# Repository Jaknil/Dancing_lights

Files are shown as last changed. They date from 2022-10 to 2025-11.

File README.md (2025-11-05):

# Dancing_lights
Dancing lights is an interactive sensitive light installation where 180 (was 300) programmable LEDs in a tube filled with crushed glass responds to movement by sensing the induced voltage from static electricity stored in people into an old TV antenna.

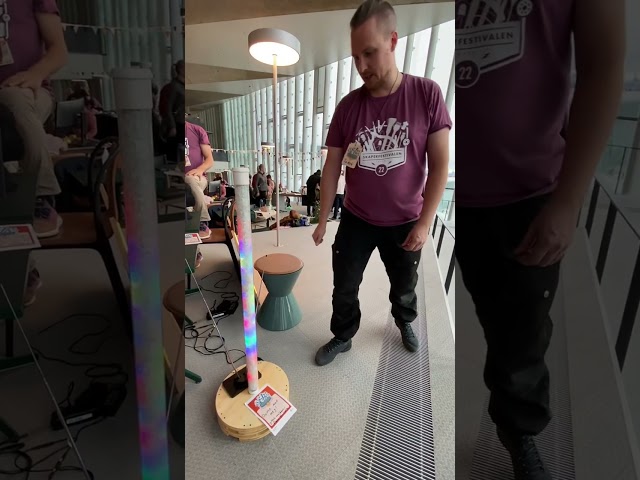
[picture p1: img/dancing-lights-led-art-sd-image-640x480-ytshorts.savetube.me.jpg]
Video demo from Skaperfesivalen (https://youtube.com/shorts/MSAI1wNTsRs)


[Video demo from Oslo skaperfestival 2022 at Deichman library](https://youtube.com/shorts/MSAI1wNTsRs)

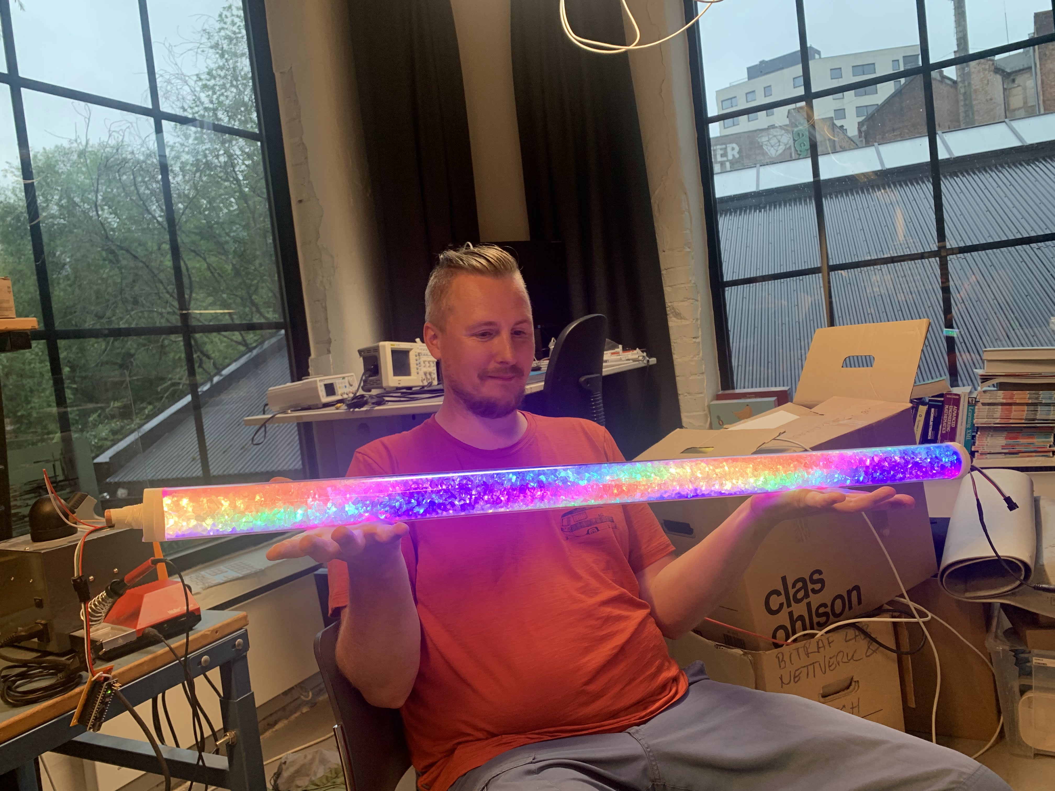
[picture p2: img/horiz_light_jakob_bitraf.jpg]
horiz_light_jakob_bitraf


## Status and todos

[Current code](code/FirstLight_dual_sensor/FirstLight_dual_sensor.ino)

120 of 300 LEDs are currently not working since I accidentally pulled off a solder-pad. Will probably have to empty it of glass to fix. The problem is in the top. 

To filter away noise the arduino ground has to be connected to ground via a capacitor (type Y). I currently solve this by using an extra power brick for a Thinkpad laptop that happens to have one built in. 

Right now it flickers quite a bit, I should look into altering the code to reduce that. (Perhaps blur or filter harder?)

## Principles and inspiration
* The glass shard filled LED diffusor tube is inspired by [Invento3Ds Instructable: Glass Stone LED Tube](https://www.instructables.com/Glass-Stone-LED-Tube-WiFi-Controlled-Through-Smart/)
* The motion sensor is based on Capacitive touch [Arduino playground: Capacitive Sensing Library
 by Paul Badger](https://playground.arduino.cc/Main/CapacitiveSensor/) and [My own lesson material on pulldown and EMC noise](https://github.com/KubenKoder/Arduino/tree/master/Egna%20exempel/pulldown)
* It uses the Arduino [FastLED library](https://fastled.io/) to make the pretty light patterns and [Scott Marleys youtube videos were priceless](https://youtube.com/playlist?list=PLgXkGn3BBAGi5dTOCuEwrLuFtfz0kGFTC) 

### Sensing movement of electric charge

Here is a video demonstrating the priciple. I use a electrostatically charged sweater to charge and discharge the antenna voltage level and having it affect which LED pixes light up. The final installation uses a prettier color mixing algorithm.

Video demonstration with statically charged sweater (https://youtube.com/shorts/0vz_sim-DHY?feature=share) 

Click to view as youtube short.

The installation can detect movement by reading the voltage on an antenna. The arms of the antenna is connected directly to an 0-5V analog input pin on the microcontroller. The signal strength is read repeatedly (around 200 times per secound) and the value is indicated by lighting up the corresponding LED-pixels on the vertical LED column, zero volts being on the bottom and 5v on top. Three pixels are lit up each time Red pixels for the raw signal strenght, Blue with some smoothing and Green pixels with heavy smoothing, using gliding averages of the signal strengh. When colors happen to overlap, they mix and if the signal is noise free and consistent it will display a white bar at some voltage between 0 and 5V. All pixels are faded over time. The effect is an interactive rainbow effect if you move an elecrical charge (like a human body) in the range of the antenna, thus indusing a voltage in the antenna. If you stand still, it will average out to a static white bar. The range and sensitivity can be tuned with the length of the antenna arms to adjust for low charge damp weather or dry electrostatically active days.

Here is a plots of the three signals beeing shown on the LED-column, when no big movements in the room change the antenna charge level. The LEDs will mix and show a bar of White light, The vertical axis represents 0-5V and adress of which LED to light up from 0-180 (180 is max since 120 of the LEDs are disabled from a broken wire). Notice the 50Hz ripple on the RawSignal plot, that translates to a red haze around the white bar in the LED column.

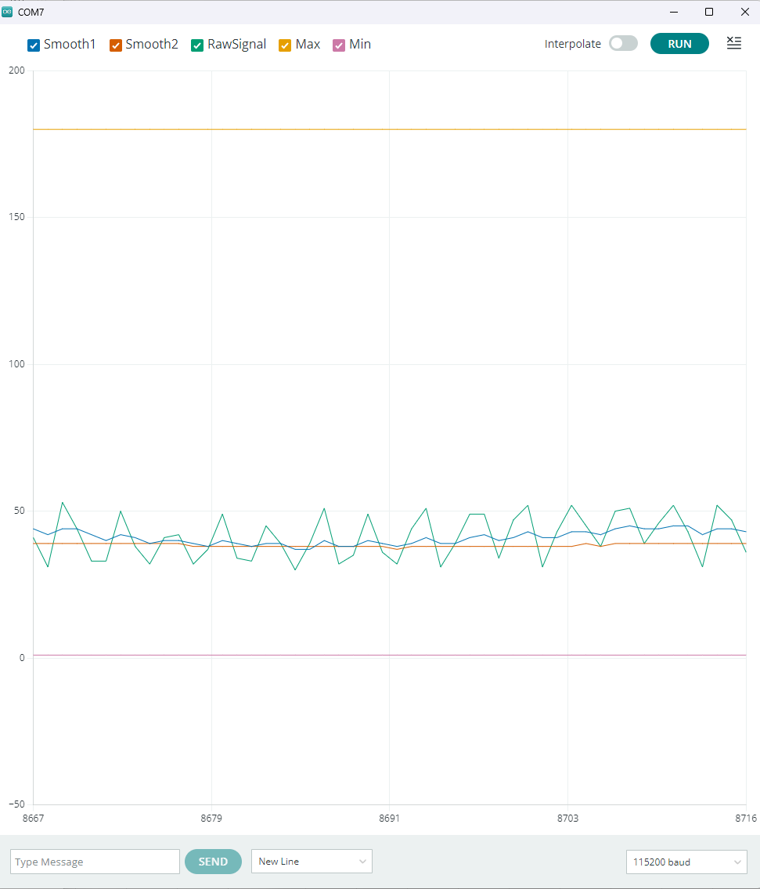
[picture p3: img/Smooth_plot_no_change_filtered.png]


Here is a plots of the three signals beeing shown on the LED-column, when a big movement in the room change the antenna charge level from min to max and then back down again. Due to the intentional "lag" from the smoothing the different colored LED being lit up at any one time will separate and create an interactive rainbow, before reverting to a white bar when the movement stops. The vertical axis represents 0-5V and adress of which LED to light up from 0-180 (180 is max since 120 of the LEDs are disabled from a broken wire).

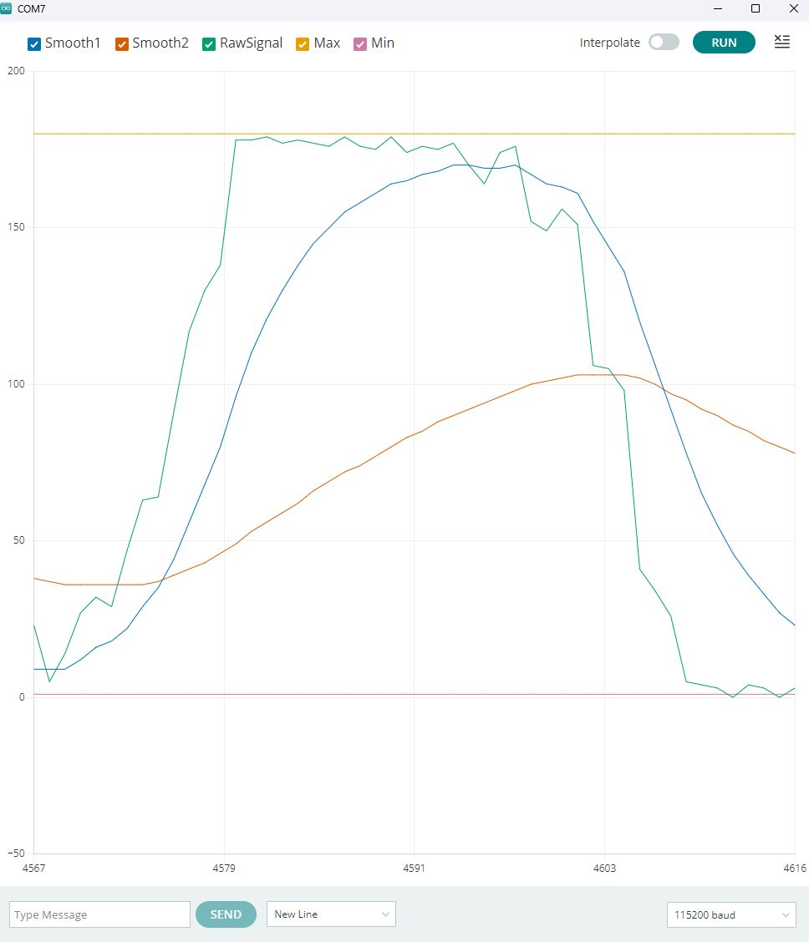
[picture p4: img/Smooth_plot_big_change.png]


### Filtering noise

Here I have disconnected the noise filtered power supply from the USB and we can se 50Hz noise clearly charging and discharging the antenna all the way to the max and min voltage lines. The smoothed signal still reflects slower movements in the room but it's somewhat drowned in the noise. The same, but much suppressed ripple can also be seen on the previous plots where I have the physical noise filter power supply connected. Finding this "hack" was a nice bonus.

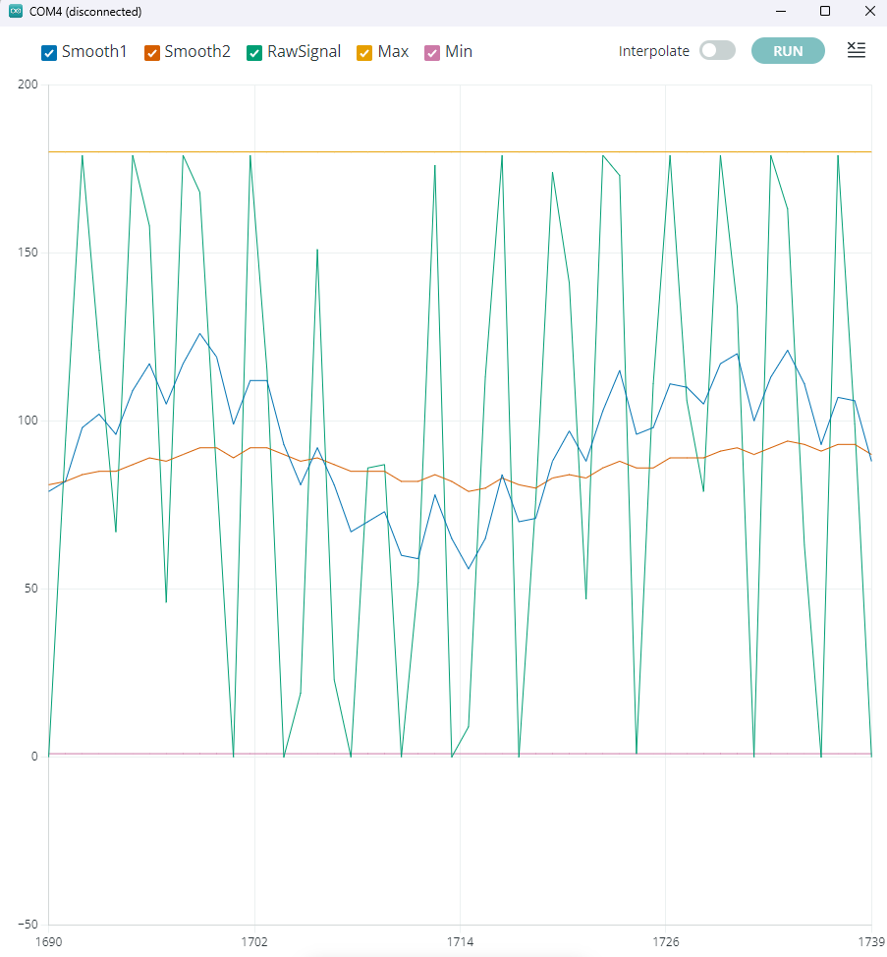
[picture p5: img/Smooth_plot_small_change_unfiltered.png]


Here is further reading on such filter capasitors: [Safety Capacitors First: Class-X and Class-Y Capacitors](https://www.allaboutcircuits.com/technical-articles/safety-capacitor-class-x-and-class-y-capacitors/)

Note to self: I should buy a filtered DC power supply and replace the chinese one we are using now. 

### Powering the LEDs

Current powering strategy:

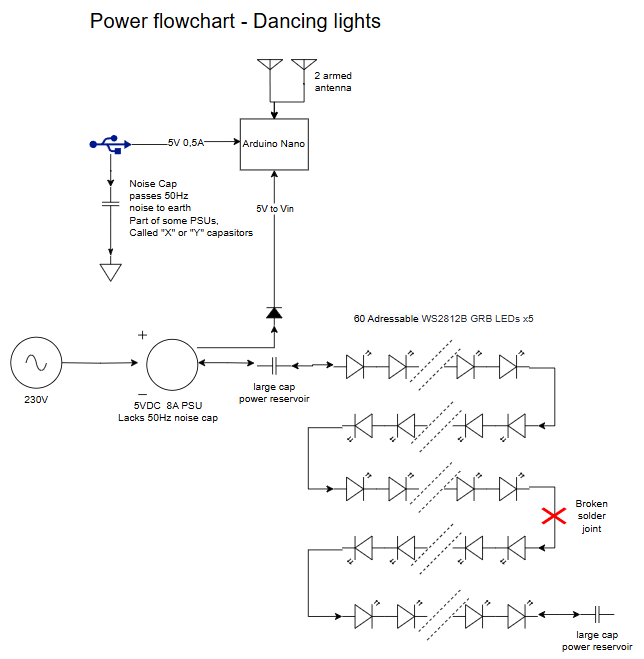
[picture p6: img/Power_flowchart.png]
Powering LEDs


Improved powering strategy, not yet implemented. This would fix the damage and reduce colour degradation from voltage drop.

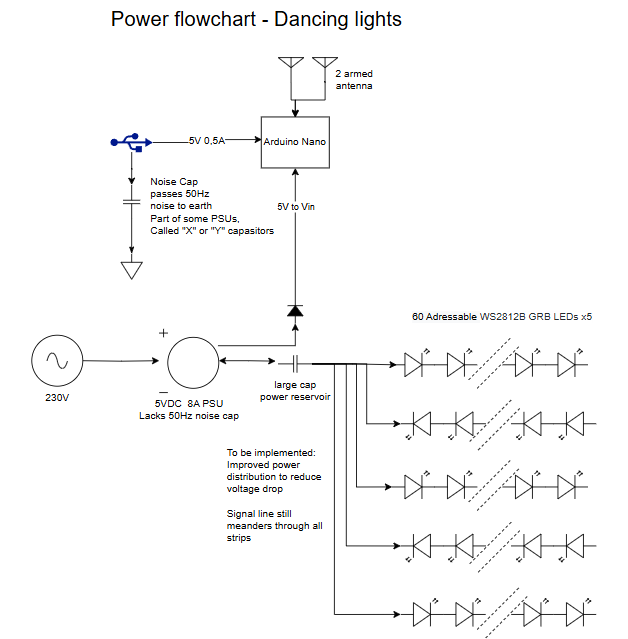
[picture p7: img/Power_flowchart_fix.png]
Powering LEDs suggested improvement


Further reference on Powering LEDs: https://learn.adafruit.com/adafruit-neopixel-uberguide/powering-neopixels

## Bill of Materials
Purchased in or imported to Norway. NOK = Norwegian kroner.

* 300 WS2812B GRB LEDs on a 5 m tape strip IP30 5V (60/m). WS2812B GRB ~$10 from [Aliexpress](https://www.aliexpress.com/item/32682015405.html) 
* 1m Ø50 mm Acrylic tube 383 NOK from [Sløjd-Detaljer](https://www.sloyd-detaljer.no/produkter/tre-metallsloyd/plast-gummi/ror-stenger/akrylror-1757)
* Used 2 kg 4-10 mm size crushed glass, 175 NOK for 3 Kg from [My stone](https://mystonebrukskunst.no/dekorasjonsglass)
* 3D-printed endcaps for the tube, modeled in Fusion360 [STL](models/50mm_plug.stl) Printed for free on a Pruse at [Bitraf makerspace](https://bitraf.no/)
* Copper tube, Ø15mm wall thickness 1.5mm, Recyled scrap. 
* 2 5V 8A Power bricks, ~10$ each from [Aliexpress](https://www.aliexpress.com/item/32986101102.html)
* 3 pin connector cheap from [Aliexpress](https://www.aliexpress.com/item/32920894203.html)
* 2 pin barrel jack connector cheap from [Aliexpress](https://www.aliexpress.com/item/32966940042.html)
* Base material TBD
* Vero-board
* Capacitors
* Antenna from flea market (According to its manual it's a FIA 137 47-68MHz, 87,5-104MHz or 174-230MHz depending on expended length but I doubt it matters in my case.) 

## Components
### 5x1m LED strips mounted on Ø15mm copper tube
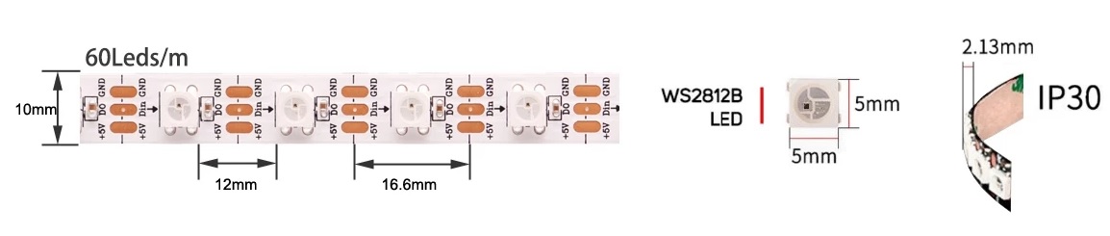
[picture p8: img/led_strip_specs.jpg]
Led strip specifications


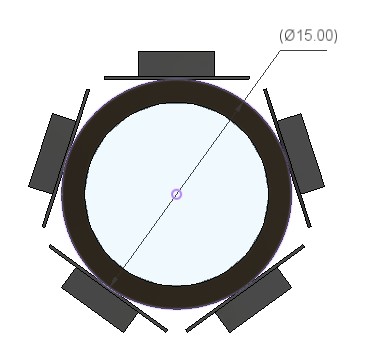
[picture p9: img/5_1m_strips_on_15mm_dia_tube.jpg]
5_1m_strips_on_15mm_dia_tube


Diameter 15mm => cicumference 47mm, 5 strips that are 10mm wide should not work in theory but works in practice since the edges don't follow the curve of the tube perfectly.
The tape attatches well to the tube. Didn't feel there was need to secure it further.

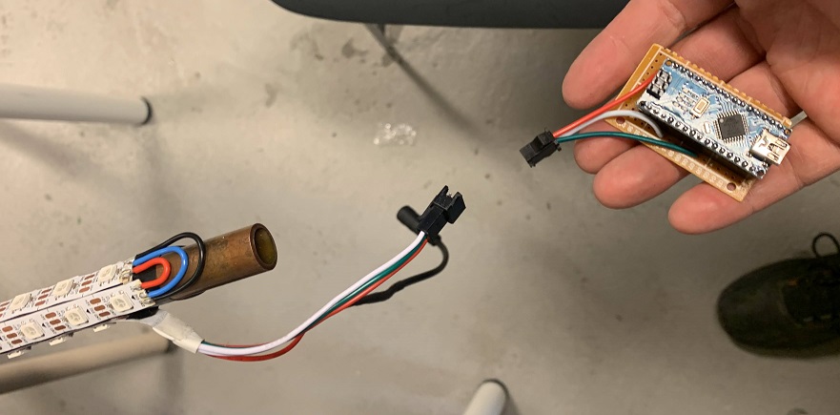
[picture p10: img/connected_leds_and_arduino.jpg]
connected_leds_and_arduino


Note that I staggered the ends of the strips. They are soldered together like as if they still were one long strip.

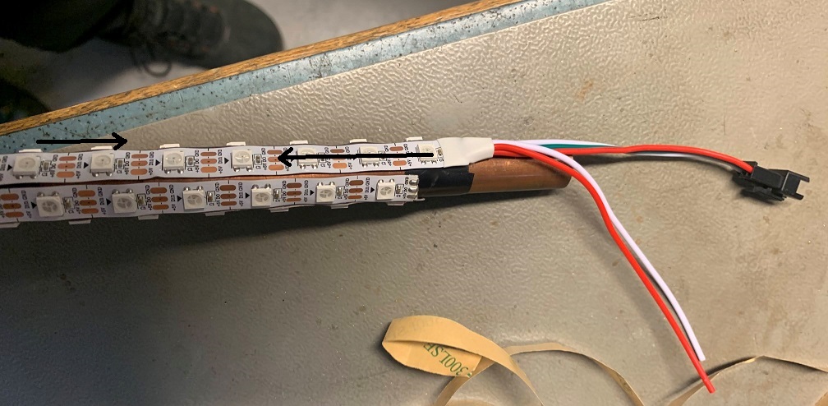
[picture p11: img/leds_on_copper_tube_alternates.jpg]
leds_on_copper_tube_alternates


Default configuration for the LED coordinates.

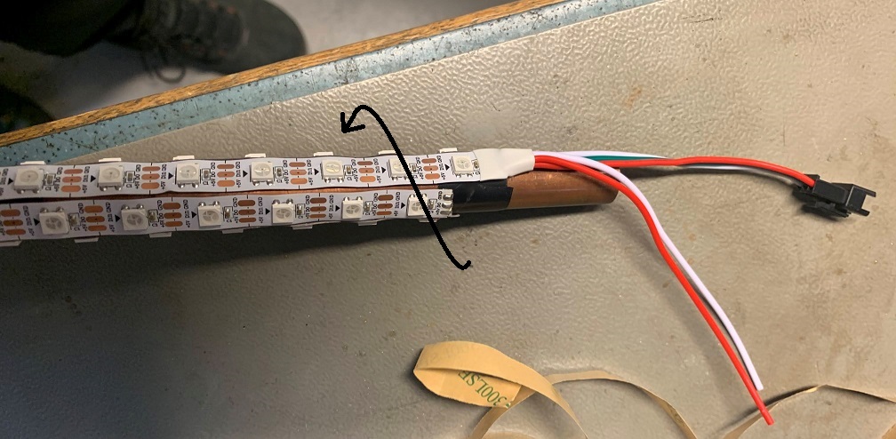
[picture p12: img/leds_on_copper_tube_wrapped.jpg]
leds_on_copper_tube_wrapped


Alternative LED coordinates increases the axial resolution from 60 leds / m to 300 leds / m. 

### Microcontroller

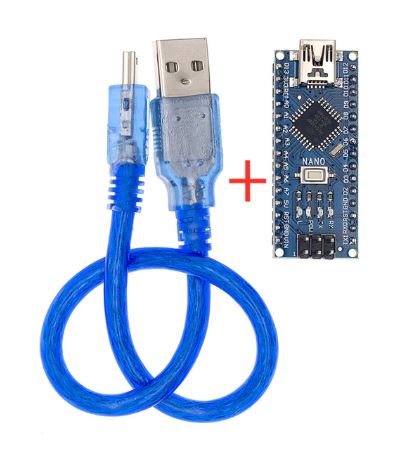
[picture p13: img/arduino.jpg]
arduino


I'm using an imported Chinese Arduino Nano with the CH40 USB to transistor logic chip. Remember to select "Old Bootloader" under processor. Herre you can download [drivers for the chip](https://github.com/KubenKoder/Arduino/blob/master/USB%20driver/README.md#usb-drivers)

### Schematic

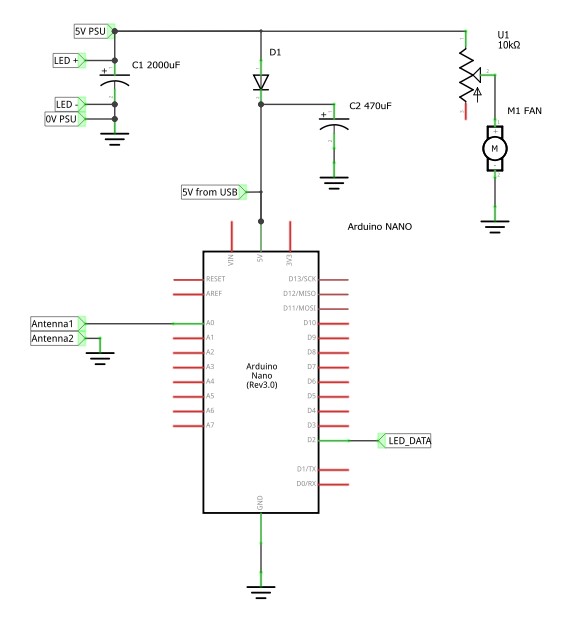
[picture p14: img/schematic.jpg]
Schematic


[Schematic pdf](Schematic.pdf)

[Schematic frizing](Schematic_fritzing.fzz)

### 3D models

fusion model

[Fusion model (online view, can be downloaded)](https://a360.co/3SHoL3g) 

[STEP file (right click and "save link as" or it will open as text](models/LED-tube_v21.step)

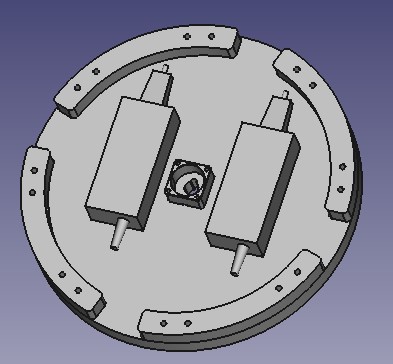
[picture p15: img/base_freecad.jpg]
base freecad


[Freecad file](models/main_shape.FCStd)

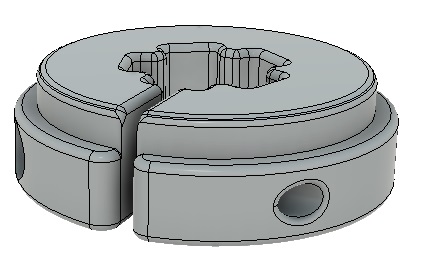
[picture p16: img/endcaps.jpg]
Tube endcaps, 3D-printed


[STL file](models/50mm_plug.stl)

The idea is to clamp the copper tube tight so that any load on the acrylic tube is transfered to the copper via the endcaps and not via the LEDs. I also want it to cover the ends of the led strips.

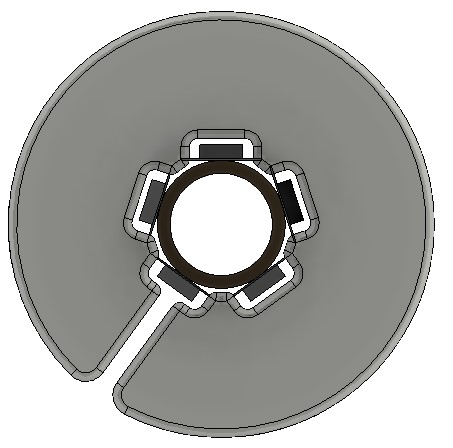
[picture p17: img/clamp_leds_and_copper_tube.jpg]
clamp_leds_and_copper_tube


Didn't fit very well. Had to file off some plastic to get it over the edges of the LED_strip tape and since I did it didn't clamp as well. Compensated with white electricans tape. I consider adding metal hose clamps.

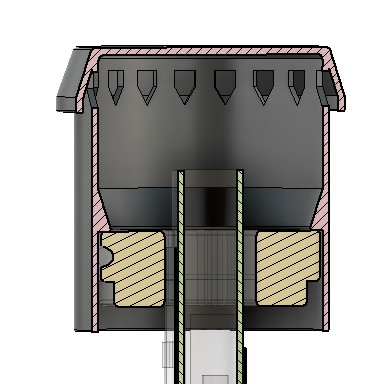
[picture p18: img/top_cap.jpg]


Concept of a top cap to hide the end and allow airflow through the pipe. Allows space for a large capacitor inside the cap, for the end of the strip. 

[STL file](models/top_cap.stl)

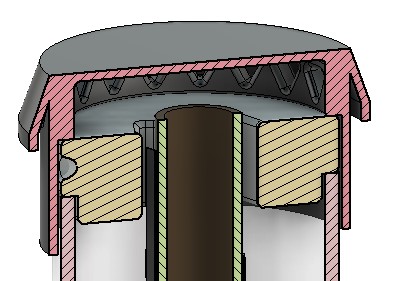
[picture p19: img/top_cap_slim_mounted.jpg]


Slim version of top cap to hide the end and allow airflow through the pipe. Requires trimming the copper pipe tight to the plastic clamp. No space for capacitor here, needs to be attached to the other ends of the strips.

[STL file](models/top_cap_slim.stl)

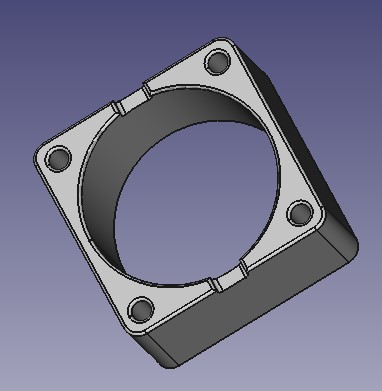
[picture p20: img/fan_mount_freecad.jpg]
fan_mount_freecad


Fan mount for bottom 

[STL file](models/fan_holder_bottom.stl)

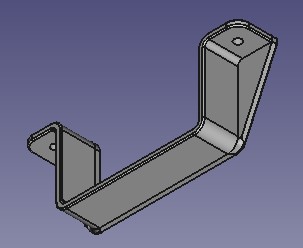
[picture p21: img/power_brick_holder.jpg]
brick holder


For holding the power bricks in place.

[STL file](models/brick_holder.stl)

## Code 

[Current code using both antennas](code/FirstLight_dual_sensor/FirstLight_dual_sensor.ino)
  
"Pacifica" and "Fire2012" are also nice when copied around the column. 

### Ideas of features to code:

#### Smooth movement between pixels
I observe that moving the leds along a full step at a time isn't very smooth. As in if I turn the next led on 100% as I turn the last to 0%. Some X-fading would be much better. Perhaps I can increase the pixel resolution articficially and spread the light between two pixels proportionally, like anti-aliasing?

#### Reduce flicker
Perhaps I can use blur or smoothe harder?

#### Beat reaction
I have not started on the code for a beat-sensor like I had intended. I have a basic idea but no code yet.
If I smoothe the same signal differently hard and compare when they cross I should be able to track a frequency. I can track amplitude also if needed but should wait with it.
I have no ready plan for what to show if I mananage to track the beat. Figure that out first?

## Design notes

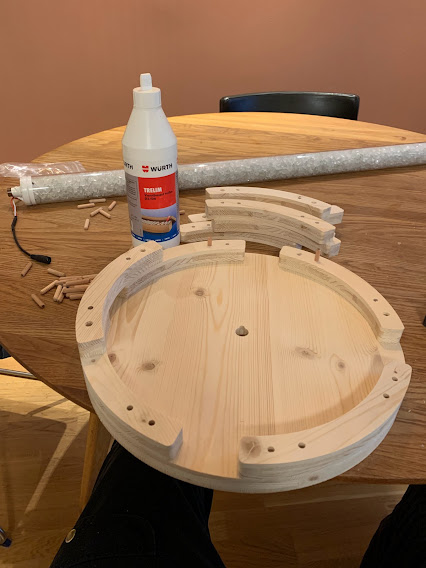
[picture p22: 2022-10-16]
img/glue_base.jpg

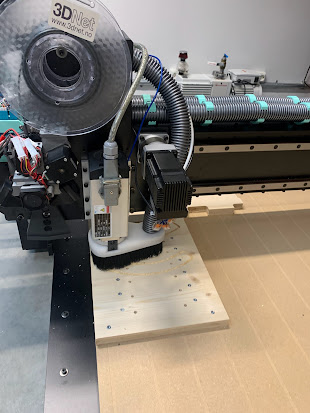
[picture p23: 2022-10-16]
img/cnc-base.jpg

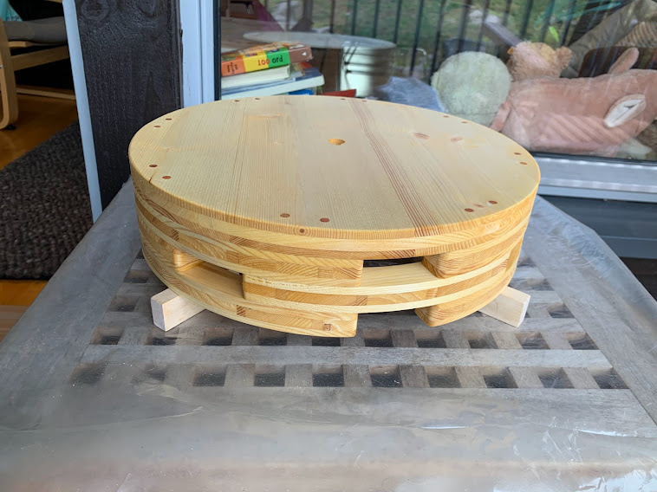
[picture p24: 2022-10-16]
img/base.jpg

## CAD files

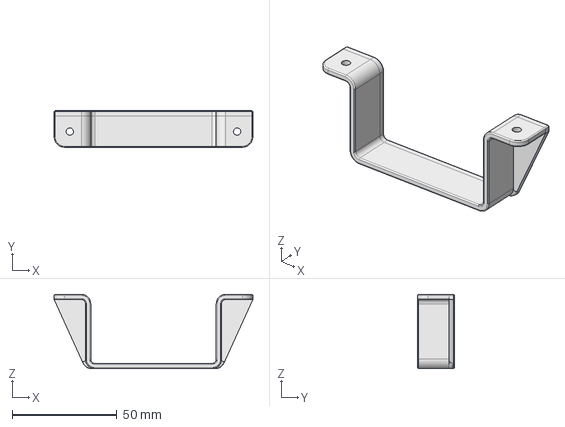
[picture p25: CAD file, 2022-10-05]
models/main_shape.FCStd
95.2 x 17.5 x 35.5 mm

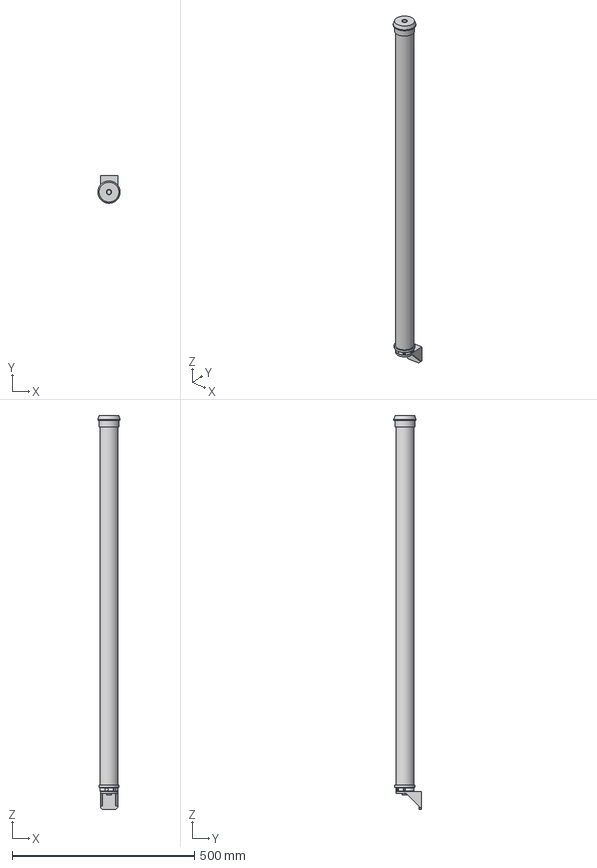
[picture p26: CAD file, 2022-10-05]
models/LED-tube_v21.step
61.3 x 75.7 x 1080.0 mm
Pipe 50mm OD clear
LEDS_3_per_100mm x 5
Copper tube core Ø15mm
Plug_clamp x 2
Mount_core
Top_cap_slim

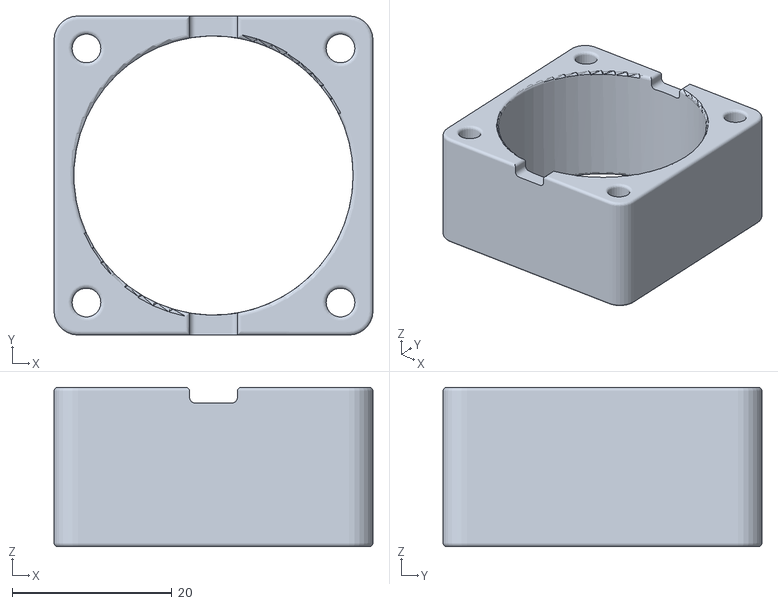
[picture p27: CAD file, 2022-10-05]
models/fan_holder_bottom.stl
40.0 x 40.0 x 20.0

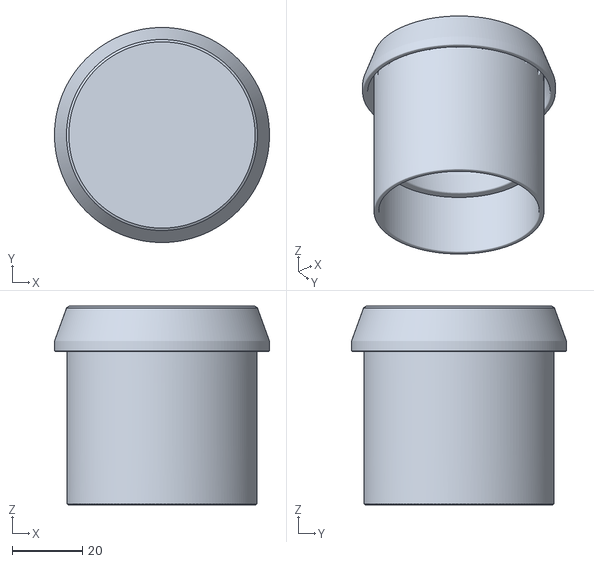
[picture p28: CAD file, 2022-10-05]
models/top_cap.stl
61.2 x 61.2 x 56.5

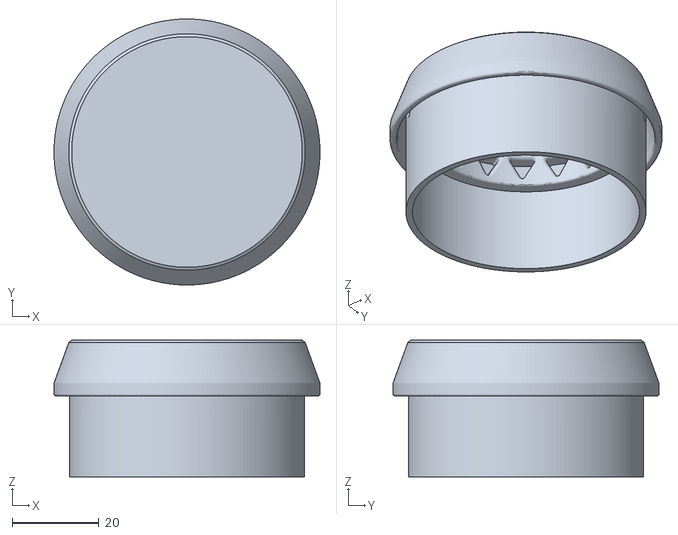
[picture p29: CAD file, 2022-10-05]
models/top_cap_slim.stl
61.4 x 61.4 x 31.5

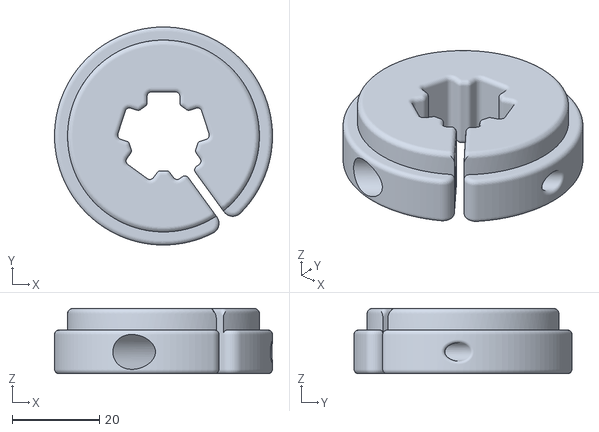
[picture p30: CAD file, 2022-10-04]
models/50mm_plug.stl
50.0 x 50.0 x 15.0

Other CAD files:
models/brick_holder.stl
models/Top_cap.f3d

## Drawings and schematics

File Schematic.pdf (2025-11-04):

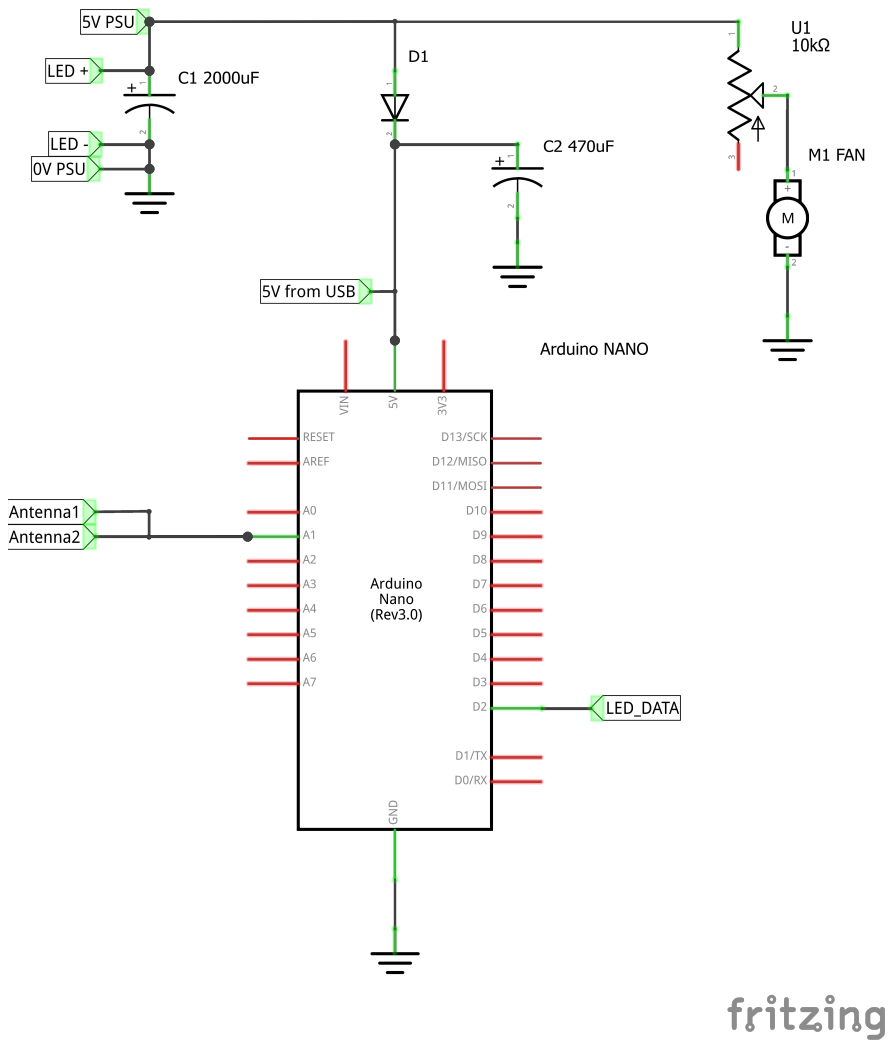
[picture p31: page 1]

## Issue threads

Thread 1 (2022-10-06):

Sensor fails if I unplug the laptop charger

Jaknil, 2022-10-06:
Situation: Arduino is connected to both the 5V 8A power brick and via USB to laptop, which in turn is connected to a grounded outlet via it's charger. = everything works fine. Even if the PC is off. However if I unplug the charger from the wall the sensor stops working. I think the laptop charger has a y cap on the secondary. See

https://electronics.stackexchange.com/questions/216959/what-does-the-y-capacitor-in-a-smps-do

Jaknil, 2023-01-06:
Solved it by using a [usb-a female to female adapter from Kjell&Co](https://www.kjell.com//no/produkter/kabler-og-kontakter/usb-kabler/dobbel-usb-hunn-p38869) to connect the charger directly to the arduino, thus removing the noise from the 0V DC rail. Need to documet it before closing this issue.

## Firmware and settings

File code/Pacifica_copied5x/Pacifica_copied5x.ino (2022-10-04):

//
//  "Pacifica"
//  Gentle, blue-green ocean waves.
//  December 2019, Mark Kriegsman and Mary Corey March.
//  For Dan.
//

#define FASTLED_ALLOW_INTERRUPTS 0
#include <FastLED.h>
FASTLED_USING_NAMESPACE

#define DATA_PIN            2
#define NUM_LEDS            60
#define NUM_LEDS_TOTAL      300

#define MAX_POWER_MILLIAMPS 5000
#define LED_TYPE            WS2812B
#define COLOR_ORDER         GRB

//////////////////////////////////////////////////////////////////////////

CRGB leds[NUM_LEDS_TOTAL];

void setup() {
  delay( 1000); // 3 second delay for boot recovery, and a moment of silence
  FastLED.addLeds<LED_TYPE,DATA_PIN,COLOR_ORDER>(leds, NUM_LEDS_TOTAL)
        .setCorrection( TypicalLEDStrip );
  FastLED.setMaxPowerInVoltsAndMilliamps( 5, MAX_POWER_MILLIAMPS);
}

void loop()
{
  EVERY_N_MILLISECONDS( 20) {
    pacifica_loop();
    copyLEDs();
    FastLED.show();
  }
}
void copyLEDs(){ //copies the settings of the first 30 leds around the stick 
  for (int i=0;i<60;i++){
  leds[i+120]=leds[i];
  leds[i+240]=leds[i];
  leds[120-1-i]=leds[i];
  leds[240-1-i]=leds[i];
}
}
//////////////////////////////////////////////////////////////////////////
//
// The code for this animation is more complicated than other examples, and 
// while it is "ready to run", and documented in general, it is probably not 
// the best starting point for learning.  Nevertheless, it does illustrate some
// useful techniques.
//
//////////////////////////////////////////////////////////////////////////
//
// In this animation, there are four "layers" of waves of light.  
//
// Each layer moves independently, and each is scaled separately.
//
// All four wave layers are added together on top of each other, and then 
// another filter is applied that adds "whitecaps" of brightness where the 
// waves line up with each other more.  Finally, another pass is taken
// over the led array to 'deepen' (dim) the blues and greens.
//
// The speed and scale and motion each layer varies slowly within independent 
// hand-chosen ranges, which is why the code has a lot of low-speed 'beatsin8' functions
// with a lot of oddly specific numeric ranges.
//
// These three custom blue-green color palettes were inspired by the colors found in
// the waters off the southern coast of California, https://goo.gl/maps/QQgd97jjHesHZVxQ7
//
CRGBPalette16 pacifica_palette_1 = 
    { 0x000507, 0x000409, 0x00030B, 0x00030D, 0x000210, 0x000212, 0x000114, 0x000117, 
      0x000019, 0x00001C, 0x000026, 0x000031, 0x00003B, 0x000046, 0x14554B, 0x28AA50 };
CRGBPalette16 pacifica_palette_2 = 
    { 0x000507, 0x000409, 0x00030B, 0x00030D, 0x000210, 0x000212, 0x000114, 0x000117, 
      0x000019, 0x00001C, 0x000026, 0x000031, 0x00003B, 0x000046, 0x0C5F52, 0x19BE5F };
CRGBPalette16 pacifica_palette_3 = 
    { 0x000208, 0x00030E, 0x000514, 0x00061A, 0x000820, 0x000927, 0x000B2D, 0x000C33, 
      0x000E39, 0x001040, 0x001450, 0x001860, 0x001C70, 0x002080, 0x1040BF, 0x2060FF };


void pacifica_loop()
{
  // Increment the four "color index start" counters, one for each wave layer.
  // Each is incremented at a different speed, and the speeds vary over time.
  static uint16_t sCIStart1, sCIStart2, sCIStart3, sCIStart4;
  static uint32_t sLastms = 0;
  uint32_t ms = GET_MILLIS();
  uint32_t deltams = ms - sLastms;
  sLastms = ms;
  uint16_t speedfactor1 = beatsin16(3, 179, 269);
  uint16_t speedfactor2 = beatsin16(4, 179, 269);
  uint32_t deltams1 = (deltams * speedfactor1) / 256;
  uint32_t deltams2 = (deltams * speedfactor2) / 256;
  uint32_t deltams21 = (deltams1 + deltams2) / 2;
  sCIStart1 += (deltams1 * beatsin88(1011,10,13));
  sCIStart2 -= (deltams21 * beatsin88(777,8,11));
  sCIStart3 -= (deltams1 * beatsin88(501,5,7));
  sCIStart4 -= (deltams2 * beatsin88(257,4,6));

  // Clear out the LED array to a dim background blue-green
  fill_solid( leds, NUM_LEDS, CRGB( 2, 6, 10));

  // Render each of four layers, with different scales and speeds, that vary over time
  pacifica_one_layer( pacifica_palette_1, sCIStart1, beatsin16( 3, 11 * 256, 14 * 256), beatsin8( 10, 70, 130), 0-beat16( 301) );
  pacifica_one_layer( pacifica_palette_2, sCIStart2, beatsin16( 4,  6 * 256,  9 * 256), beatsin8( 17, 40,  80), beat16( 401) );
  pacifica_one_layer( pacifica_palette_3, sCIStart3, 6 * 256, beatsin8( 9, 10,38), 0-beat16(503));
  pacifica_one_layer( pacifica_palette_3, sCIStart4, 5 * 256, beatsin8( 8, 10,28), beat16(601));

  // Add brighter 'whitecaps' where the waves lines up more
  pacifica_add_whitecaps();

  // Deepen the blues and greens a bit
  pacifica_deepen_colors();
}

// Add one layer of waves into the led array
void pacifica_one_layer( CRGBPalette16& p, uint16_t cistart, uint16_t wavescale, uint8_t bri, uint16_t ioff)
{
  uint16_t ci = cistart;
  uint16_t waveangle = ioff;
  uint16_t wavescale_half = (wavescale / 2) + 20;
  for( uint16_t i = 0; i < NUM_LEDS; i++) {
    waveangle += 250;
    uint16_t s16 = sin16( waveangle ) + 32768;
    uint16_t cs = scale16( s16 , wavescale_half ) + wavescale_half;
    ci += cs;
    uint16_t sindex16 = sin16( ci) + 32768;
    uint8_t sindex8 = scale16( sindex16, 240);
    CRGB c = ColorFromPalette( p, sindex8, bri, LINEARBLEND);
    leds[i] += c;
  }
}

// Add extra 'white' to areas where the four layers of light have lined up brightly
void pacifica_add_whitecaps()
{
  uint8_t basethreshold = beatsin8( 9, 55, 65);
  uint8_t wave = beat8( 7 );
  
  for( uint16_t i = 0; i < NUM_LEDS; i++) {
    uint8_t threshold = scale8( sin8( wave), 20) + basethreshold;
    wave += 7;
    uint8_t l = leds[i].getAverageLight();
    if( l > threshold) {
      uint8_t overage = l - threshold;
      uint8_t overage2 = qadd8( overage, overage);
      leds[i] += CRGB( overage, overage2, qadd8( overage2, overage2));
    }
  }
}

// Deepen the blues and greens
void pacifica_deepen_colors()
{
  for( uint16_t i = 0; i < NUM_LEDS; i++) {
    leds[i].blue = scale8( leds[i].blue,  145); 
    leds[i].green= scale8( leds[i].green, 200); 
    leds[i] |= CRGB( 2, 5, 7);
  }
}

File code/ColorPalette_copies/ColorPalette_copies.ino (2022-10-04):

#include <FastLED.h>

#define LED_PIN     2
#define NUM_LEDS    60
#define NUM_LEDS_STRIP 300
#define BRIGHTNESS  96
#define LED_TYPE    WS2812B
#define COLOR_ORDER GRB
CRGB leds[NUM_LEDS_STRIP];

#define UPDATES_PER_SECOND 100

// This example shows several ways to set up and use 'palettes' of colors
// with FastLED.
//
// These compact palettes provide an easy way to re-colorize your
// animation on the fly, quickly, easily, and with low overhead.
//
// USING palettes is MUCH simpler in practice than in theory, so first just
// run this sketch, and watch the pretty lights as you then read through
// the code.  Although this sketch has eight (or more) different color schemes,
// the entire sketch compiles down to about 6.5K on AVR.
//
// FastLED provides a few pre-configured color palettes, and makes it
// extremely easy to make up your own color schemes with palettes.
//
// Some notes on the more abstract 'theory and practice' of
// FastLED compact palettes are at the bottom of this file.



CRGBPalette16 currentPalette;
TBlendType    currentBlending;

extern CRGBPalette16 myRedWhiteBluePalette;
extern const TProgmemPalette16 myRedWhiteBluePalette_p PROGMEM;


void setup() {
    delay( 3000 ); // power-up safety delay
    FastLED.addLeds<LED_TYPE, LED_PIN, COLOR_ORDER>(leds, NUM_LEDS_STRIP).setCorrection( TypicalLEDStrip );
    FastLED.setBrightness(  BRIGHTNESS );
    
    currentPalette = RainbowColors_p;
    currentBlending = LINEARBLEND;
}
void copyLEDs(){ //copies the settings of the first 30 leds around the stick 
  for (int i=0;i<60;i++){
  leds[i+120]=leds[i];
  leds[i+240]=leds[i];
  leds[120-1-i]=leds[i];
  leds[240-1-i]=leds[i];
}
}

void loop()
{
    ChangePalettePeriodically();
    
    static uint8_t startIndex = 0;
    startIndex = startIndex + 1; /* motion speed */
    
    FillLEDsFromPaletteColors( startIndex);
    copyLEDs();
    FastLED.show();
    FastLED.delay(1000 / UPDATES_PER_SECOND);
}

void FillLEDsFromPaletteColors( uint8_t colorIndex)
{
    uint8_t brightness = 255;
    
    for( int i = 0; i < NUM_LEDS; ++i) {
        leds[i] = ColorFromPalette( currentPalette, colorIndex, brightness, currentBlending);
        colorIndex += 3;
    }
}


// There are several different palettes of colors demonstrated here.
//
// FastLED provides several 'preset' palettes: RainbowColors_p, RainbowStripeColors_p,
// OceanColors_p, CloudColors_p, LavaColors_p, ForestColors_p, and PartyColors_p.
//
// Additionally, you can manually define your own color palettes, or you can write
// code that creates color palettes on the fly.  All are shown here.

void ChangePalettePeriodically()
{
    uint8_t secondHand = (millis() / 1000) % 60;
    static uint8_t lastSecond = 99;
    
    if( lastSecond != secondHand) {
        lastSecond = secondHand;
        if( secondHand ==  0)  { currentPalette = RainbowColors_p;         currentBlending = LINEARBLEND; }
        if( secondHand == 10)  { currentPalette = RainbowStripeColors_p;   currentBlending = NOBLEND;  }
        if( secondHand == 15)  { currentPalette = RainbowStripeColors_p;   currentBlending = LINEARBLEND; }
        if( secondHand == 20)  { SetupPurpleAndGreenPalette();             currentBlending = LINEARBLEND; }
        if( secondHand == 25)  { SetupTotallyRandomPalette();              currentBlending = LINEARBLEND; }
        if( secondHand == 30)  { SetupBlackAndWhiteStripedPalette();       currentBlending = NOBLEND; }
        if( secondHand == 35)  { SetupBlackAndWhiteStripedPalette();       currentBlending = LINEARBLEND; }
        if( secondHand == 40)  { currentPalette = CloudColors_p;           currentBlending = LINEARBLEND; }
        if( secondHand == 45)  { currentPalette = PartyColors_p;           currentBlending = LINEARBLEND; }
        if( secondHand == 50)  { currentPalette = myRedWhiteBluePalette_p; currentBlending = NOBLEND;  }
        if( secondHand == 55)  { currentPalette = myRedWhiteBluePalette_p; currentBlending = LINEARBLEND; }
    }
}

// This function fills the palette with totally random colors.
void SetupTotallyRandomPalette()
{
    for( int i = 0; i < 16; ++i) {
        currentPalette[i] = CHSV( random8(), 255, random8());
    }
}

// This function sets up a palette of black and white stripes,
// using code.  Since the palette is effectively an array of
// sixteen CRGB colors, the various fill_* functions can be used
// to set them up.
void SetupBlackAndWhiteStripedPalette()
{
    // 'black out' all 16 palette entries...
    fill_solid( currentPalette, 16, CRGB::Black);
    // and set every fourth one to white.
    currentPalette[0] = CRGB::White;
    currentPalette[4] = CRGB::White;
    currentPalette[8] = CRGB::White;
    currentPalette[12] = CRGB::White;
    
}

// This function sets up a palette of purple and green stripes.
void SetupPurpleAndGreenPalette()
{
    CRGB purple = CHSV( HUE_PURPLE, 255, 255);
    CRGB green  = CHSV( HUE_GREEN, 255, 255);
    CRGB black  = CRGB::Black;
    
    currentPalette = CRGBPalette16(
                                   green,  green,  black,  black,
                                   purple, purple, black,  black,
                                   green,  green,  black,  black,
                                   purple, purple, black,  black );
}


// This example shows how to set up a static color palette
// which is stored in PROGMEM (flash), which is almost always more
// plentiful than RAM.  A static PROGMEM palette like this
// takes up 64 bytes of flash.
const TProgmemPalette16 myRedWhiteBluePalette_p PROGMEM =
{
    CRGB::Red,
    CRGB::Gray, // 'white' is too bright compared to red and blue
    CRGB::Blue,
    CRGB::Black,
    
    CRGB::Red,
    CRGB::Gray,
    CRGB::Blue,
    CRGB::Black,
    
    CRGB::Red,
    CRGB::Red,
    CRGB::Gray,
    CRGB::Gray,
    CRGB::Blue,
    CRGB::Blue,
    CRGB::Black,
    CRGB::Black
};



// Additional notes on FastLED compact palettes:
//
// Normally, in computer graphics, the palette (or "color lookup table")
// has 256 entries, each containing a specific 24-bit RGB color.  You can then
// index into the color palette using a simple 8-bit (one byte) value.
// A 256-entry color palette takes up 768 bytes of RAM, which on Arduino
// is quite possibly "too many" bytes.
//
// FastLED does offer traditional 256-element palettes, for setups that
// can afford the 768-byte cost in RAM.
//
// However, FastLED also offers a compact alternative.  FastLED offers
// palettes that store 16 distinct entries, but can be accessed AS IF
// they actually have 256 entries; this is accomplished by interpolating
// between the 16 explicit entries to create fifteen intermediate palette
// entries between each pair.
//
// So for example, if you set the first two explicit entries of a compact 
// palette to Green (0,255,0) and Blue (0,0,255), and then retrieved 
// the first sixteen entries from the virtual palette (of 256), you'd get
// Green, followed by a smooth gradient from green-to-blue, and then Blue.

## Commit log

2022-10-04 Wrote BOM
    [50mm_plug.stl]
2022-10-04 Upload of freecad model
    [main_shape.FCStd]
2022-10-04 added more code
    [led_order.xlsx]
2022-10-05 Updated thicknessness
    [main_shape.FCStd]
2022-10-05 Added models for printing
    [LED-tube_v21.step, Top_cap.f3d, brick_holder.stl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]
2022-10-06 power flowchart
2022-10-16 Dual sensor with wrapped pixels
2023-01-04 Added schematic
    [Schematic_fritzing.fzz]
2023-01-04 Update README.md
    Added links and schematic pic
2023-01-06 Create arduino.jpg
    nano pic
2025-11-04 Corrected Pinout and added explanations
    [Schematic_fritzing.fzz]
2025-11-05 Corrected power flowchart
